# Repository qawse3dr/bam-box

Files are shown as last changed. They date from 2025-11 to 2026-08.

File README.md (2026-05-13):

# Bam Box
Bam box is a CD player and ripper created from a RPI4 running QNX 8.0. It is made up of a USB CD player powered from an external USB power hub, 2 cheap speaker, a SPI LCD, and a tiny I2S DAC doing it's best. All of the 3D models can be found under [models](./models/) 

[Project Page](https://www.larrycloud.ca/project/BamBox)

## Photos
> For more photos see project page

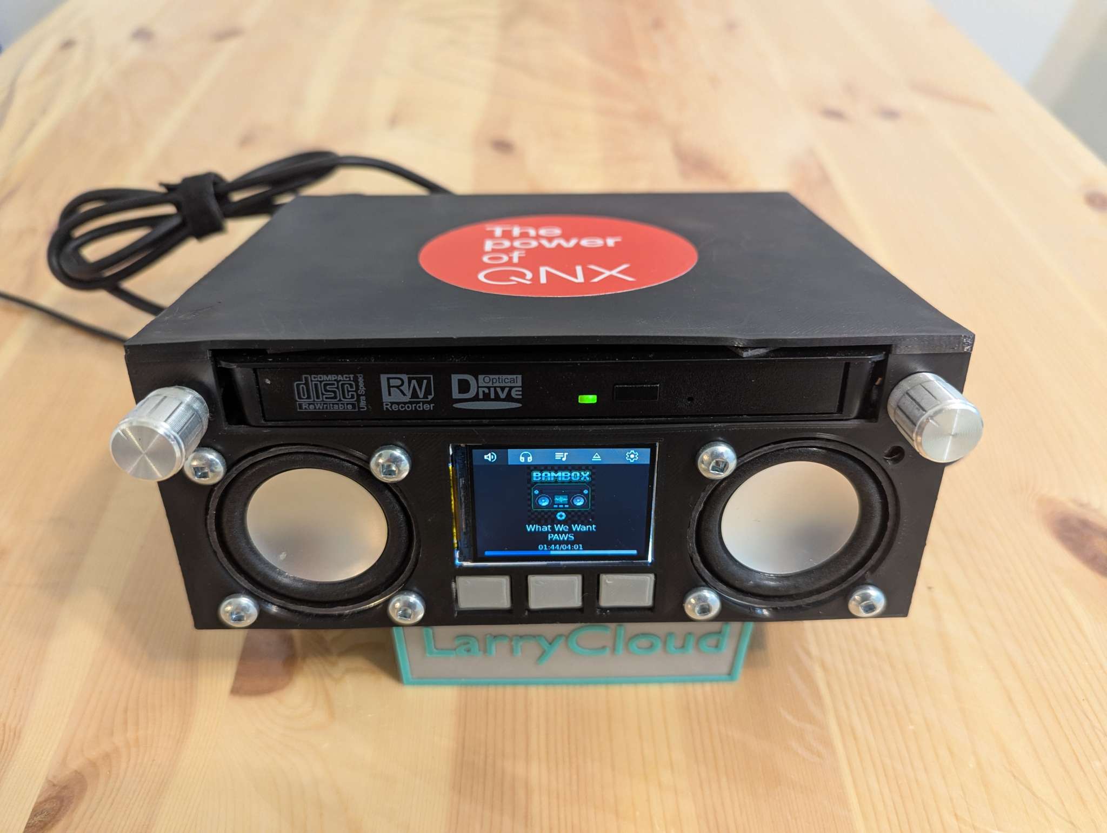
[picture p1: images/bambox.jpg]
Bam Box


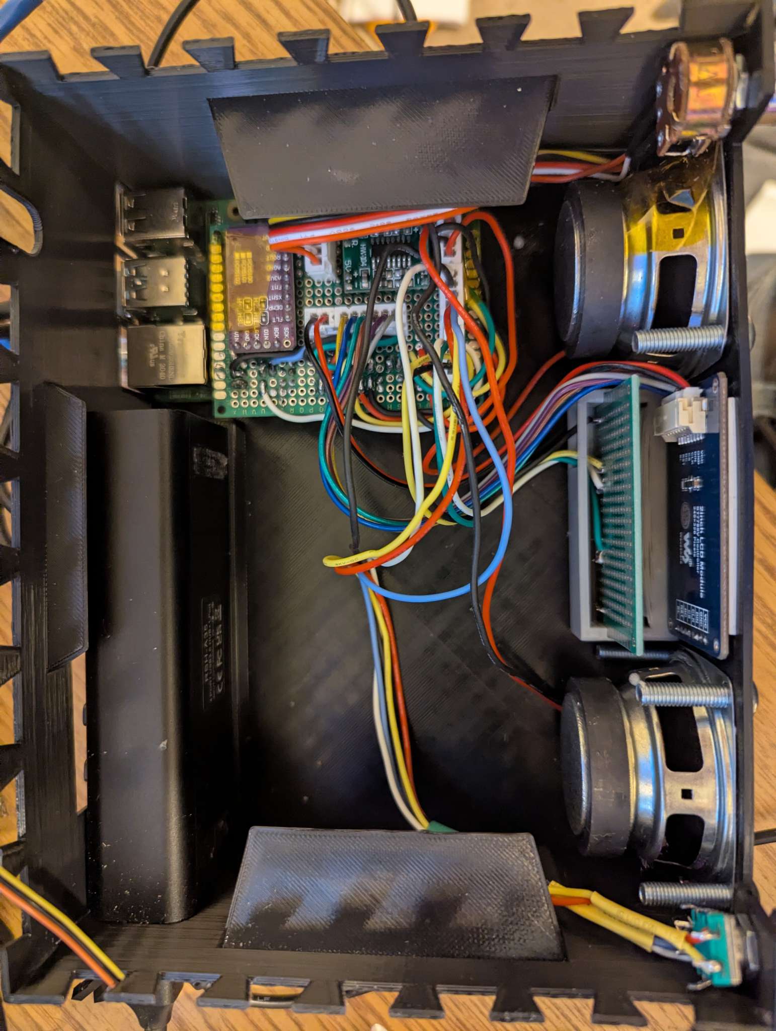
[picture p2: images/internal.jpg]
Bam Box Internals


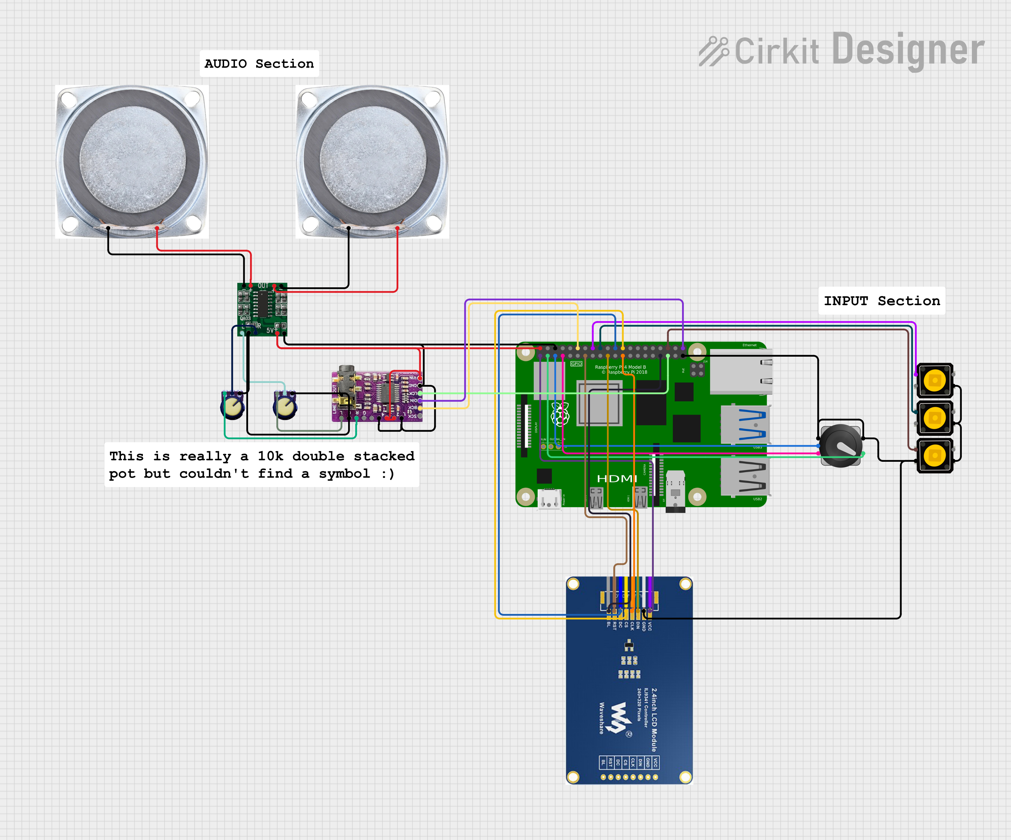
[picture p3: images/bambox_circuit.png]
Bam Box Circut


## Hardware
| Component | Parts |
| --- | --- |
| Board | RPI4 |
| OS | QNX 8.0 CTI image |
| Amplifier | [104-HW (PAM8403)](https://www.amazon.ca/HiLetgo-PAM8403-Digital-Amplifier-2-5-5V/dp/B00LODGV64) |
| Audio DAC | [PCM5102](https://www.adafruit.com/product/6250) (I didn't use Adafruit but this should work fine. WARNING the jack is line out not headphone out :) ) |
| Speakers | [Gikfun 2 inch 4Ohm 3W](https://gikfun.com/products/gikfun-2-4ohm-3w-full-range-audio-speaker-stereo-woofer-loudspeaker-for-arduino-pack-of-2pcs) |
| LCD | [Waveshare 2inch SPI LCD Module](https://www.pishop.ca/product/240x320-general-2inch-ips-lcd-display-module) |
| Powered USB Hub | [ICAN 5 port power hub](https://www.canadacomputers.com/en/usb-hubs/260489/ican-5-port-usb-3-0-hub-with-12v-2a-power-adapter-rsh-a35.html) |
| Rotary Encoder  | Simple rotary encoder with push button |
| Push button | 3 push buttons for media controls |
| Volume knob | 10k dual stacked potentiator |

## Building
QNX aarch64 cross toolchain file can be found [here](https://github.com/qnx-ports/build-files/blob/main/ports/vsomeip/qnx.nto.toolchain.cmake)

### Prereqs

#### spdlog
In order to build you first need to build and install spdlog which can be done doing the following with your SDP sourced.
```bash
git clone https://github.com/gabime/spdlog.git && cd spdlog
mkdir build_qnx
cmake \
  -DCMAKE_TOOLCHAIN_FILE=../../aarch64-qnx.cmake \
  -DCMAKE_INSTALL_PREFIX=${QNX_TARGET} \
  -DCMAKE_INSTALL_INCLUDEDIR=usr/local/include \
  -DCMAKE_INSTALL_LIBDIR=aarch64le/usr/local/lib \
  -DCMAKE_INSTALL_BINDIR=aarch64le/usr/local/bin \
  -DCMAKE_SHARED_LINKER_FLAGS=-lsocket \
  -DCMAKE_EXE_LINKER_FLAGS=-lsocket \
  ..
make install
```
#### curl
libcurl is used for downloading album art and info as well as uploading to WebDAV. It can be installed from QSC

#### libdiscid
Every disc as a hash which can be calculated based on it's table of contents. This is widely used in order to identify CD's that are missing CD Texts. Too read more about this see [Musicbrainz docs](https://musicbrainz.org/doc/Disc_ID_Calculation)
```
git clone https://github.com/metabrainz/libdiscid.git
cd libdiscid && mkdir build && cd build
cmake \
  -DCMAKE_TOOLCHAIN_FILE=../../aarch64-qnx.cmake \
  -DCMAKE_INSTALL_PREFIX=${QNX_TARGET} \
  -DCMAKE_INSTALL_INCLUDEDIR=usr/local/include \
  -DCMAKE_INSTALL_LIBDIR=aarch64le/usr/local/lib \
  -DCMAKE_INSTALL_BINDIR=aarch64le/usr/local/bin \
  -DCMAKE_SHARED_LINKER_FLAGS=-lsocket \
  -DCMAKE_EXE_LINKER_FLAGS=-lsocket \
```

#### GTK4
The GUI is all driven using GTK4

For instruction for building GTK4 see [qnx-ports](https://github.com/qnx-ports/build-files/tree/main/ports/gtk)

#### FLAC
libFLAC and libFLAC++ are used when dumping songs from the CD. Currently only the libs can be built cleanly so the cli tool's were disabled for the purpose of this project
```
git clone https://github.com/xiph/flac.git
cd flac && mkdir build && cd build
cmake \
  -DCMAKE_TOOLCHAIN_FILE=../../aarch64-qnx.cmake \
  -DCMAKE_INSTALL_PREFIX=${QNX_TARGET} \
  -DCMAKE_INSTALL_INCLUDEDIR=usr/local/include \
  -DCMAKE_INSTALL_LIBDIR=aarch64le/usr/local/lib \
  -DCMAKE_INSTALL_BINDIR=aarch64le/usr/local/bin \
  -DCMAKE_SHARED_LINKER_FLAGS=-lsocket \
  -DCMAKE_EXE_LINKER_FLAGS=-lsocket \
  -DWITH_OGG=OFF \
  -DINSTALL_MANPAGES=OFF \
  -DBUILD_PROGRAMS=OFF \
  ..
make install
```

#### nlohmann JSON
nlohmann JSON is a header only library for C++ which is considered the standard for anything JSON. it's header can be download from the [releases tab](https://github.com/nlohmann/json/releases) on Github.

### Building
This repo makes use of QNX's recursive make which can be build by simply typing make. After it is build the artifacts
will be created under nto/aarch64/o.le
```
JLEVEL=4 make
```

## Running
> Sample configuration file can be found here: [etc/bambox.jsonc](./etc/bambox.jsonc)
```
mkdir bambox-info # holds cached images and song metadata
export XDG_DATA_DIRS=/data/home/qnxuser/share
export GSK_RENDERER=gl
./bam-box --config=bambox.jsonc
```

### Features

- [x] Playing music from CD
- [x] Display CD information
  - [x] Album Art
  - [x] Artist, Song, Album
  - [ ] Lyrics
- [x] Auto fetch album information and art from DB
- [x] Software Volume Controls
- [x] Audio output selection 
  - [x] PCM (headphones)
  - [x] I2S (speakers)
  - [ ] USB (usb headphone)
- [x] CD Eject
- [x] Album track selection
- [x] Settings
  - [x] In UI update
    - [x] Default output
    - [x] Default Soft Volume
    - [x] Dark/Light Mode
  - [x] About BamBox page
  - [x] About CD page
  - [x] JSON config file
  - [x] Dump FLAC files
    - [x] Upload to webdav server

### Architecture

#### Display
The LCD uses a virtual screen to receive data rendered from GTK4, which is then written to the screen over SPI. The DC pin is used to indicate whether the data being sent is a command or display data. The flow looks like this:
```mermaid 
%%{init: { 'theme':'dark', 'sequence': {'useMaxWidth':false} } }%%
sequenceDiagram
  participant BamBox
  participant GTK4
  participant screen
  participant SPI_LCD as SPI LCD

  BamBox ->> SPI_LCD: Setup Commands
  BamBox ->> screen: Open frame buffer

  loop Render Loop
    BamBox ->> GTK4: Draw UI
    GTK4 ->> screen: Render to virtual display
    screen ->> BamBox: screen_read_display()
    BamBox ->> SPI_LCD: DC(1)
    activate SPI_LCD
    BamBox ->> SPI_LCD: write()
    BamBox ->> SPI_LCD: DC(0)
    deactivate SPI_LCD
  end
```
In this sequence, GTK4 renders the interface to a virtual display device. BamBox reads the rendered frame and sends it over SPI to the LCD, using the DC pin to differentiate between commands and pixel data.

#### CD and Audio path

```mermaid
%%{init: { 'theme':'dark', 'sequence': {'useMaxWidth':false} } }%%
sequenceDiagram
  participant BamBox
  participant CD_Player as CD Player
  participant CD_Reader as CD Reader
  participant Audio_Player as Audio Player
  participant MusicBrainz

  BamBox ->> CD_Player: Load
  activate CD_Player
  CD_Player ->> CD_Reader: Load disc
  activate CD_Reader
  CD_Reader ->> CD_Reader: Calculate discid
  CD_Reader ->> MusicBrainz: Fetch metadata and album art
  deactivate CD_Reader
  CD_Player ->> BamBox: Disc loaded callback
  deactivate CD_Player

  BamBox ->> CD_Player: Play track 1
  activate CD_Player
  loop Playback Loop
    CD_Player ->> CD_Reader: Read track data
    activate CD_Reader
    CD_Reader ->> Audio_Player: Write PCM data
    activate Audio_Player
    deactivate Audio_Player
    deactivate CD_Reader
  end
  deactivate CD_Player
```

### Improvements
- [ ] Finish custom BSP that can be build from a single cmd
- [ ] Create AudioSink and AudioSource which have a read and a write function so we can  have multiple sources in the future such as CDPlayer, Bluetooth player, usb player.
AudioSource should also have the ability to get song info, and tracks.
- [ ] There is no error checking for uploading to the server.
- [ ] Remove LCD class and correctly implement LCD openWFD driver.

## Lessons Learned

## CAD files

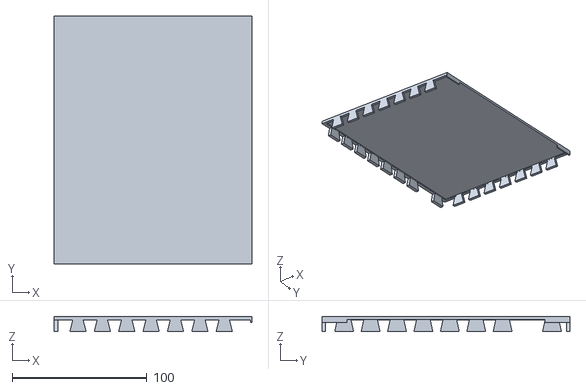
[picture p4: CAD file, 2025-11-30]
models/cdplayer_lid.stl
146.6 x 184.1 x 11.1

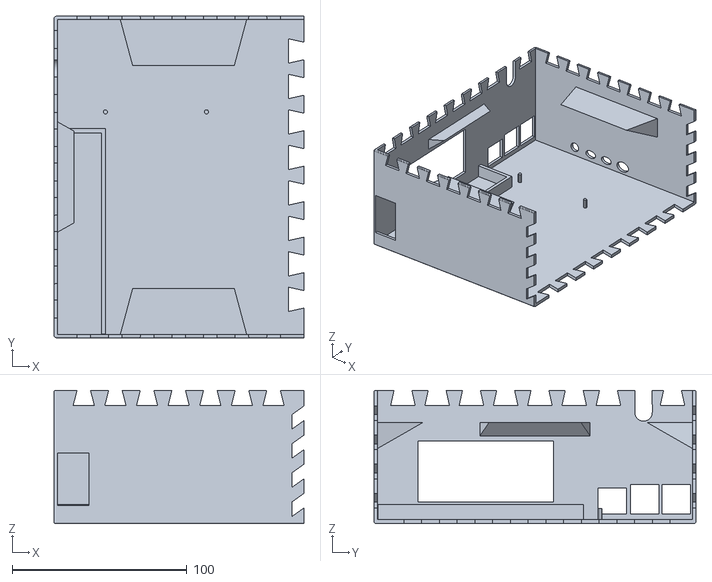
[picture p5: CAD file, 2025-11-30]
models/cdplayer_body.stl
143.0 x 184.0 x 76.3

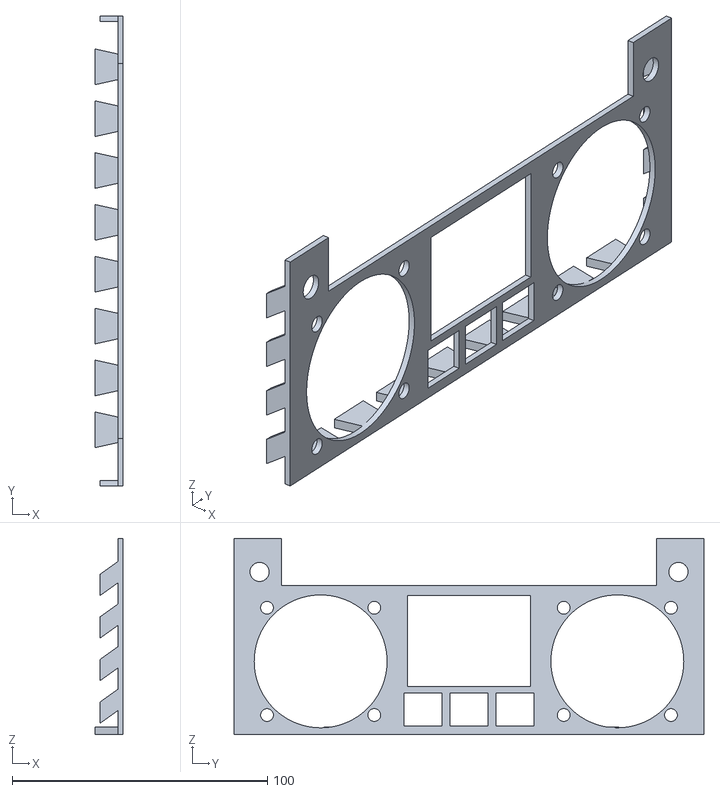
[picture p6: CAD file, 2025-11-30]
models/cdplayer_front.stl
11.0 x 184.0 x 76.8

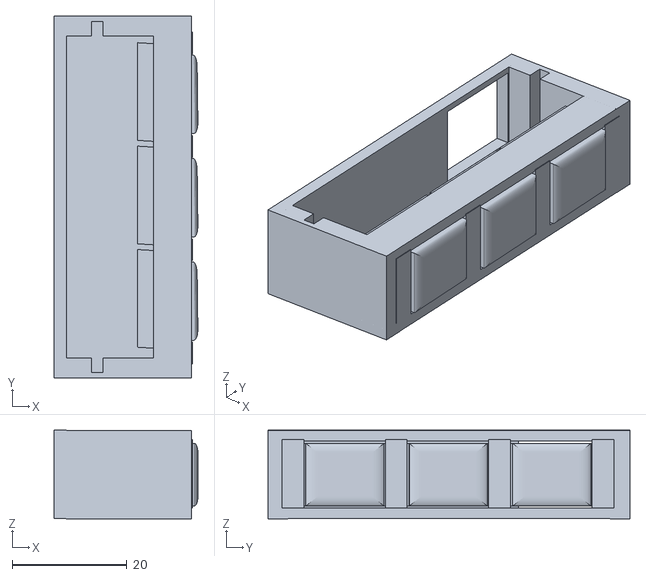
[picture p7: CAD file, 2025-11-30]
models/cdplayer_buttons.stl
25.0 x 63.0 x 15.4

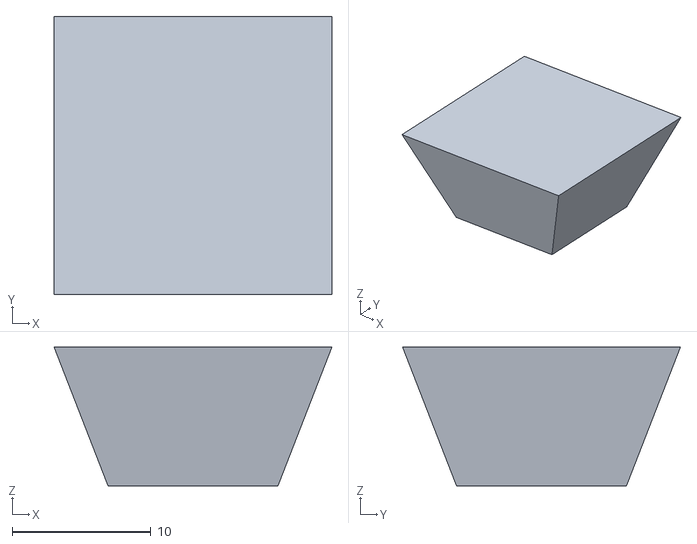
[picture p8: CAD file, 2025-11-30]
models/cdplayer_feet.stl
20.0 x 20.0 x 10.0

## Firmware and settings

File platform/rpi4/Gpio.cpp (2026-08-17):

/*
 * Copyright (C) 2025 Larry Milne (https://www.larrycloud.ca)
 *
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
 * THE SOFTWARE IS PROVIDED "AS IS", WITHOUT WARRANTY OF ANY KIND, EXPRESS OR
 * IMPLIED, INCLUDING BUT NOT LIMITED TO THE WARRANTIES OF MERCHANTABILITY,
 * FITNESS FOR A PARTICULAR PURPOSE AND NONINFRINGEMENT. IN NO EVENT SHALL THE
 * AUTHORS OR COPYRIGHT HOLDERS BE LIABLE FOR ANY CLAIM, DAMAGES OR OTHER
 * LIABILITY, WHETHER IN AN ACTION OF CONTRACT, TORT OR OTHERWISE, ARISING FROM,
 * OUT OF OR IN CONNECTION WITH THE SOFTWARE OR THE USE OR OTHER DEALINGS IN THE
 * SOFTWARE.
 */

/**
 * Based on https://datasheets.raspberrypi.com/bcm2711/bcm2711-peripherals.pdf
 * chatper 5
 */
#include "platform/Gpio.hpp"

#include <sys/mman.h>
#include <sys/neutrino.h>

#include <cerrno>
#include <chrono>
#include <cstdint>
#include <iostream>

#define BCM2711_GPIO_BASE 0xfe200000
#define BLOCK_SIZE (4 * 1024)

#define GPIO_SET 7
#define GPIO_CLR 10
#define GPIO_READ 13
#define GPIO_PULL_SET 57
#define GPIO_PULL_NONE 0
#define PULL_DOWN 2
#define PULL_UP 1

#define GPIO_GPEDS0 0x40 / 4  // GPIO event detection register
#define GPIO_GPREN0 0x4c / 4  // GPIO rising edge detection enable
#define GPIO_GPFEN0 0x58 / 4  // GPIO falling edge detection enable
#define GPIO_GPHEN0 0x64 / 4  // GPIO high level detection enable
#define GPIO_GPLEN0 0x70 / 4  // GPIO low level detection enable

#define GPIO_BANK0_IRQ 145

using bambox::platform::Gpio;

Gpio::Gpio() = default;
Gpio::~Gpio() {
  // The IST is blocked in InterruptWait() and can't be woken, so ask it to exit
  // and detach. Unmapping here would pull the registers out from under it, so
  // leave the mapping for process exit to reclaim.
  ist_running_ = false;
  if (gpio_ist_thread_.joinable()) {
    gpio_ist_thread_.detach();
  }
}

int Gpio::init() {
  gpio_base_ = (volatile uint32_t *)mmap_device_memory(NULL, BLOCK_SIZE, PROT_NOCACHE | PROT_READ | PROT_WRITE, 0,
                                                       BCM2711_GPIO_BASE);
  if (gpio_base_ == MAP_FAILED) {
    gpio_base_ = NULL;
    return errno;
  }

  ist_running_ = true;
  gpio_ist_thread_ = std::thread(&Gpio::gpio_ist_func, this);
  return EOK;
}

void Gpio::level_set(unsigned int gpio, bool high) {
  auto *level_ptr = gpio_base_ + ((high) ? GPIO_SET : GPIO_CLR);
  *level_ptr = (0x1u << gpio);
}
bambox::Expected<Gpio::GpioIRQHandle> Gpio::register_irq(unsigned int gpio, std::set<TriggerType> type,
                                                         GpioIRQ irq_func, std::chrono::nanoseconds debounce_timeout) {
  // Disable all of them
  *(gpio_base_ + GPIO_GPREN0) &= ~(1 << gpio);
  *(gpio_base_ + GPIO_GPFEN0) &= ~(1 << gpio);
  *(gpio_base_ + GPIO_GPHEN0) &= ~(1 << gpio);
  *(gpio_base_ + GPIO_GPLEN0) &= ~(1 << gpio);
  *(gpio_base_ + GPIO_GPEDS0) = (1U << gpio);  // Clear the event (write 1 to clear)

  if (type.count(TriggerType::RISING_EDGE)) {
    *(gpio_base_ + GPIO_GPREN0) |= (1 << gpio);
  }

  if (type.count(TriggerType::FALLING_EDGE)) {
    *(gpio_base_ + GPIO_GPFEN0) |= (1 << gpio);
  }

  if (type.count(TriggerType::HIGH_LEVEL)) {
    *(gpio_base_ + GPIO_GPHEN0) |= (1 << gpio);
  }

  if (type.count(TriggerType::LOW_LEVEL)) {
    *(gpio_base_ + GPIO_GPLEN0) |= (1 << gpio);
  }

  static GpioIRQHandle next_handle = 0;
  std::lock_guard<std::mutex> lk(irq_mutex_);
  GpioIRQHandle handle = next_handle++;
  // insert() would silently keep the old handler, so overwrite instead.
  irq_map_.insert_or_assign(gpio, (IRQInfo){irq_func, handle, debounce_timeout});
  return {handle};
}

int Gpio::level_get(unsigned int gpio) { return (*(gpio_base_ + GPIO_READ) >> gpio) & 0x1; }

void Gpio::pull_mode_set(unsigned int gpio, PullMode mode) {
  uint32_t pullreg = (GPIO_PULL_SET + (gpio >> 4));
  const uint32_t pullshift = (uint32_t)((gpio & 0xf) << 1);
  unsigned int pullbits = *(gpio_base_ + pullreg);
  pullbits &= ~(3 << pullshift);
  pullbits |= (static_cast<int>(mode) << pullshift);
  *(gpio_base_ + pullreg) = pullbits;
}

Gpio::PullMode Gpio::pull_mode_get(unsigned int gpio) {
  const uint32_t pull_reg = *(gpio_base_ + GPIO_PULL_SET + (gpio >> 4));
  PullMode mode = static_cast<PullMode>((pull_reg >> ((gpio & 0xf) << 1)) & 0x3);
  return mode;
}

void Gpio::alt_func_set(unsigned int gpio, AltFunc alt_func) {
  uint32_t reg = gpio / 10;
  const uint32_t sel = gpio % 10;
  uint32_t val;
  val = *(gpio_base_ + reg);
  val &= ~(0x7 << (3 * sel));
  val |= (static_cast<int>(alt_func) & 0x7) << (3 * sel);
  *(gpio_base_ + reg) = val;
}

Gpio::AltFunc Gpio::alt_func_get(unsigned int gpio) {
  const uint32_t reg = gpio / 10;
  const uint32_t sel = gpio % 10;
  return static_cast<AltFunc>(((*(gpio_base_ + reg)) >> (3 * sel)) & 0x7);
}
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

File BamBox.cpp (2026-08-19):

/*
 * Copyright (C) 2025 Larry Milne (https://www.larrycloud.ca)
 *
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
 * THE SOFTWARE IS PROVIDED "AS IS", WITHOUT WARRANTY OF ANY KIND, EXPRESS OR
 * IMPLIED, INCLUDING BUT NOT LIMITED TO THE WARRANTIES OF MERCHANTABILITY,
 * FITNESS FOR A PARTICULAR PURPOSE AND NONINFRINGEMENT. IN NO EVENT SHALL THE
 * AUTHORS OR COPYRIGHT HOLDERS BE LIABLE FOR ANY CLAIM, DAMAGES OR OTHER
 * LIABILITY, WHETHER IN AN ACTION OF CONTRACT, TORT OR OTHERWISE, ARISING FROM,
 * OUT OF OR IN CONNECTION WITH THE SOFTWARE OR THE USE OR OTHER DEALINGS IN THE
 * SOFTWARE.
 */

#include "BamBox.hpp"

#include <spdlog/spdlog.h>
#include <sys/dcmd_cam.h>

#include <algorithm>
#include <chrono>
#include <filesystem>
#include <iomanip>
#include <iostream>
#include <memory>
#include <mutex>

#include "AudioPlayer.hpp"
#include "BamBoxError.hpp"
#include "CdReader.hpp"
#include "FlacWriter.hpp"
#include "platform/Gpio.hpp"
#include "util/WebDAV.hpp"

using bambox::BamBox;

namespace {
// GTK ID's

// Screens
const char* GID_SCREEN_STACK = "screen-stack";
const char* GID_SCREEN_STACK_SPLASH_SCREEN = "splash-screen";
const char* GID_SCREEN_STACK_MAIN_SCREEN = "main-screen";
const char* GID_SCREEN_STACK_SETTING_SCREEN = "setting-screen";

// Menu Buttons
const char* GID_MENU_BUTTONS_VOLUME = "volume-menu-button";
const char* GID_MENU_BUTTONS_OUTPUT = "output-menu-button";
const char* GID_MENU_BUTTONS_TRACKS = "tracks-menu-button";
const char* GID_MENU_BUTTONS_EJECT = "eject-menu-button";
const char* GID_MENU_BUTTONS_SETTINGS = "settings-menu-button";

// Settings Buttons
const char* GID_SETTING_WIN = "setting-win";
const char* GID_SETTING_WIN_CONTENT = "setting-win-content";
const char* GID_SETTING_BUTTONS_VOLUME = "volume-settings-button";
const char* GID_SETTING_BUTTONS_OUTPUT = "output-settings-button";
const char* GID_SETTING_BUTTONS_THEME = "theme-settings-button";
const char* GID_SETTING_BUTTONS_DUMP = "dump-settings-button";
const char* GID_SETTING_BUTTONS_REFETCH = "refetch-metadata-settings-button";
const char* GID_SETTING_BUTTONS_CD_INFO = "cd-info-setting-button";
const char* GID_SETTING_BUTTONS_ABOUT = "about-setting-button";
const char* GID_SETTING_BUTTONS_RESTART = "restart-setting-button";

// Settings Labels
const char* GID_SETTING_LABEL_OUTPUT = "output-settings-label";
const char* GID_SETTING_LABEL_VOLUME = "volume-settings-label";
const char* GID_SETTING_SWITCH_THEME = "theme-settings-switch";
const char* GID_SETTING_LABEL_DUMP = "dump-settings-label";

// song info
const char* GID_SONG_INFO_ALBUM_ART = "album-art";
const char* GID_SONG_INFO_TRACK_NAME = "track-name-text";
const char* GID_SONG_INFO_ALBUM_TEXT = "album-text";
const char* GID_SONG_INFO_ARTIST_TEXT = "artist-text";
const char* GID_SONG_INFO_PROGRESS = "song-progress";

// Overlays
const char* GID_OVERLAY_VOLUME = "volume-overlay";
const char* GID_OVERLAY_OUTPUT = "output-overlay";
const char* GID_OVERLAY_TRACKS = "tracks-overlay";

// Settings Overlays
const char* GID_SETTING_OVERLAY_OUTPUT = "setting-output-overlay";
const char* GID_SETTING_OVERLAY_VOLUME = "setting-volume-overlay";
const char* GID_SETTING_OVERLAY_DUMP = "setting-dump-overlay";
const char* GID_SETTING_OVERLAY_CD_INFO = "setting-cd-info-overlay";
const char* GID_SETTING_OVERLAY_ABOUT = "setting-about-overlay";

// Volume overlay
const char* GID_OVERLAY_VOLUME_PROGRESS = "volume-progress";

// Output Overlay
const char* GID_OVERLAY_OUTPUT_LIST = "output-overlay-list";

// Tracks Overlay
const char* GID_OVERLAY_TRACKS_LIST = "tracks-overlay-list";
const char* GID_OVERLAY_TRACKS_WIN = "tracks-overlay-window";

// Settings - Audio Device
const char* GID_SETTING_OVERLAY_OUTPUT_LIST = "setting-output-overlay-list";

// Settings - DUMP
const char* GID_SETTING_OVERLAY_DUMP_CANCEL = "dump-cancel-button";
const char* GID_SETTING_OVERLAY_DUMP_ACCEPT = "dump-accept-button";
const char* GID_SETTING_OVERLAY_ALBUM_LABEL = "settings-dump-overlay-title";
const char* GID_SETTING_OVERLAY_TRACK_LABEL = "settings-dump-overlay-tracks";
const char* GID_SETTING_OVERLAY_SONG_PROGRESS = "dump-song-progress";
const char* GID_SETTING_OVERLAY_DISC_PROGRESS = "dump-disc-progress";

// Settings - Volume
const char* GID_SETTING_OVERLAY_VOLUME_PROGRESS = "setting-volume-progress";

// Settings - CD Info Overlay
const char* GID_SETTING_OVERLAY_CD_INFO_ALBUM_NAME = "cd-info-album-name";
const char* GID_SETTING_OVERLAY_CD_INFO_ARTIST_NAME = "cd-info-artist-name";
const char* GID_SETTING_OVERLAY_CD_INFO_TRACK_COUNT = "cd-info-track-count";
const char* GID_SETTING_OVERLAY_CD_INFO_ALBUM_LENGTH = "cd-info-length";
const char* GID_SETTING_OVERLAY_CD_INFO_RELEASE_DATE = "cd-info-release-date";
const char* GID_SETTING_OVERLAY_CD_INFO_ALBUM_ART = "cd-info-album-art";

const char* DEFAULT_IMAGE_PATH = "/ca/larrycloud/bambox/ui/res/logo.png";

}  // namespace

BamBox::BamBox() {}
BamBox::~BamBox() {}

bambox::Error BamBox::config(BamBoxConfig&& cfg) {
  spdlog::info("Configuring...");
  cfg_ = std::move(cfg);
  cd_reader_ = std::make_shared<CdReader>(cfg_);
  audio_player_ = std::make_shared<AudioPlayer>();
  cd_player_ = std::make_unique<CdPlayer>(
      cd_reader_, audio_player_,
      std::bind(&BamBox::cd_player_event, this, std::placeholders::_1, std::placeholders::_2));
  gpio_ = std::make_shared<platform::Gpio>();
  lcd_display_ = std::make_unique<LcdDisplay>(gpio_);

  spdlog::info("Configuring GPIO");
  if (gpio_->init() != 0) {
    return {ECode::ERR_IO, "Failed it initialize GPIO are you root?"};
  }

  // Must be done after GPIO as it makes use of it
  spdlog::info("Configuring Display");
  auto res = lcd_display_->init();
  if (res.is_error()) {
    return res;
  }

  spdlog::info("Configuring Audio");
  for (const auto& audio_dev : cfg_.audio_devs) {
    // Ignore devices in case one isn't attached
    audio_player_->create_device(audio_dev);
  }
  audio_player_->select_device(cfg_.default_audio_dev);

  return {};
}
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

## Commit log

2025-11-30 Add 3d models and get basic controls working
    [cdplayer_body.stl, cdplayer_buttons.stl, cdplayer_feet.stl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]
2025-12-08 Rework CD flow
    Fix workflow so BamBox class controls gpio, cdReader and AudioPlayer
    [BamBox.cpp, Gpio.cpp]
2025-12-09 add vscode options and implement rotary encoder
2026-01-16 add eject button
2026-01-18 Update to using ui file for loading GUI
    Description:
    - Should have feature parity as before but adding new ui elements should
    be much faster. as it now uses the ui builder.
    - icons need to be fixed as 2 use the system icon which looks bad. also
    button don't fully look correct.
    - added splash screen with AI generated logo as placeholder
    [BamBox.cpp]
2026-01-26 fix image not being displayed if unknown
    [BamBox.cpp]
2026-02-10 fix icons and startup missfire
    [BamBox.cpp, Gpio.cpp]
2026-02-18 Add select song icon
    DESCRIPTION:
    - Started to add config and command line.
    - Rework how list work in gtk and added song select
    [BamBox.cpp, BamBoxConfig.cpp]
2026-02-18 BUGFIX: long titles in track select
    [BamBox.cpp]
2026-02-19 Update Setting Screen
    - Refactor UI to have a stack with pop func to make pop code more generic
    - Start implementing the setting screen allowing selection between buttons
    - Next we need to make button selection generic so it can be used in all button screens
    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
2026-02-20 Add theming and fix config dumping and reading
    [BamBox.cpp, BamBoxConfig.cpp]
2026-02-24 Update setting to select default audio device and volume, and album info
2026-02-24 fix output overlay in setting menu
    [BamBox.cpp]
2026-02-27 Finish BamBox v1.0
    - Adds uploading to webdav server
    - fix last couple bugs
    - update readme with parts
    - Add images to readme
    [BamBox.cpp, BamBoxConfig.cpp]
2026-03-02 Fix bug with incorrect progress
    [BamBox.cpp]
